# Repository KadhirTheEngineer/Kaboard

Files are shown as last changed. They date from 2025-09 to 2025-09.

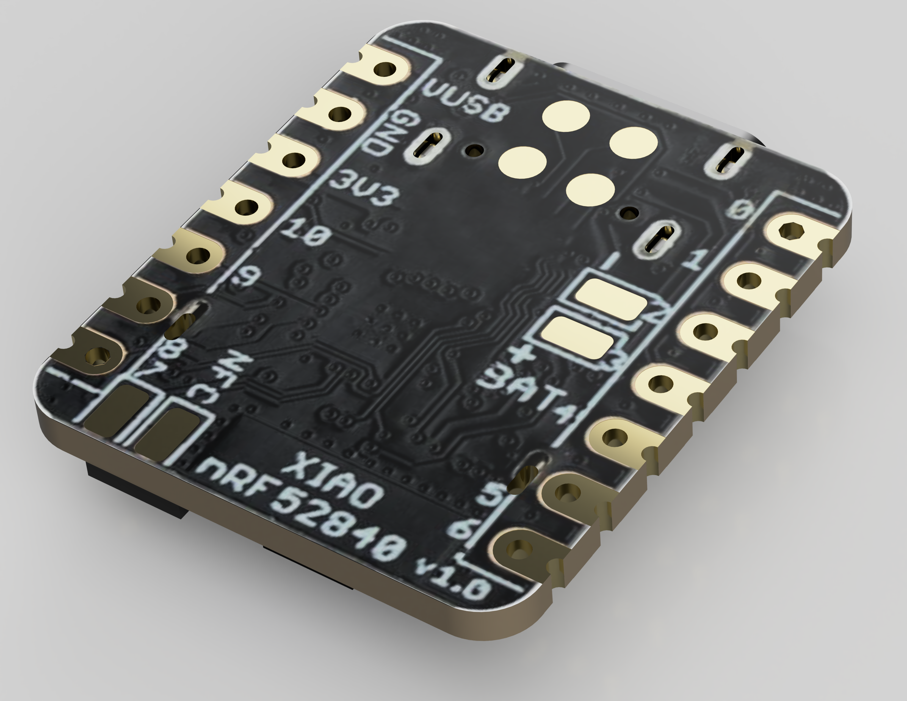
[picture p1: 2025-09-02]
mech/seeed-studio-xiao-nrf52840-1.snapshot.5/XIAO-nRF52840_2023-Jun-02_08-50-46AM-000_CustomizedView56582366354.png

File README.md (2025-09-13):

# Kaboard

An ultra-low profile 36-key wireless split keyboard with the Seeed XIAO nrf52840 dev board. Low power and insane battery life. 



Based on the chocofi and wireless corne.

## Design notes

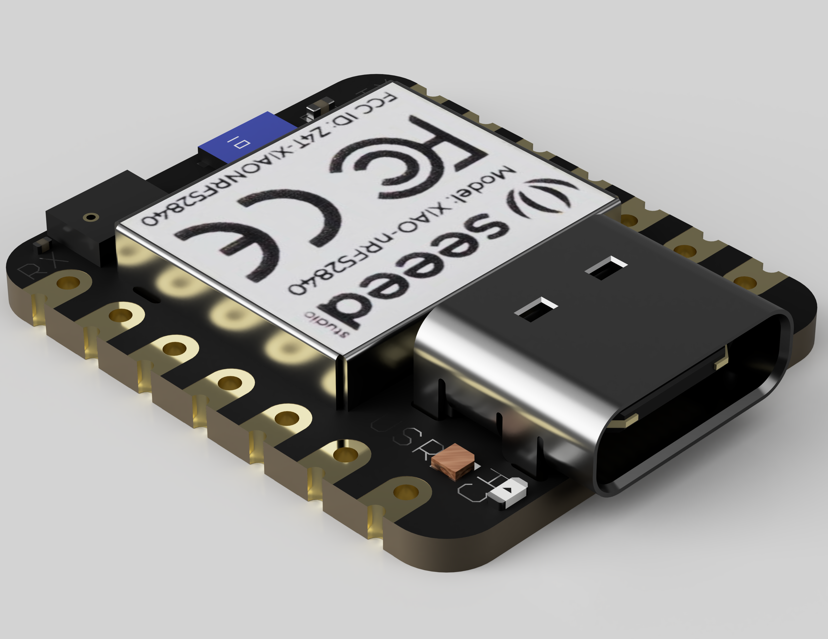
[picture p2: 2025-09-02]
mech/seeed-studio-xiao-nrf52840-1.snapshot.5/XIAO-nRF52840_2023-May-29_10-38-12PM-000_CustomizedView20313148104.png

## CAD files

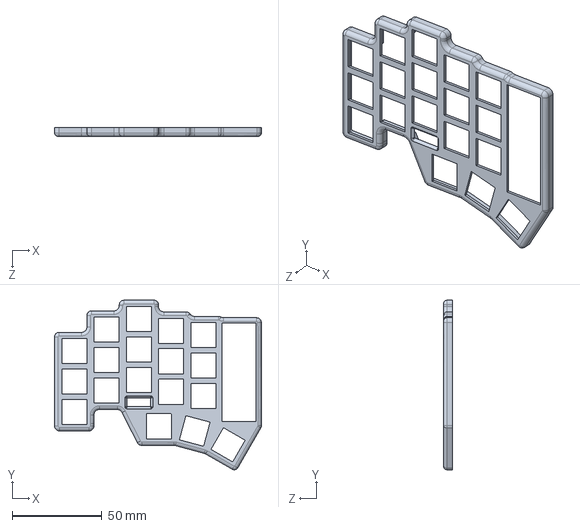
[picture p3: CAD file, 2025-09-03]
mech/case/switchplate_1_2mm_test.SLDPRT
115.4 x 94.6 x 5.00 mm

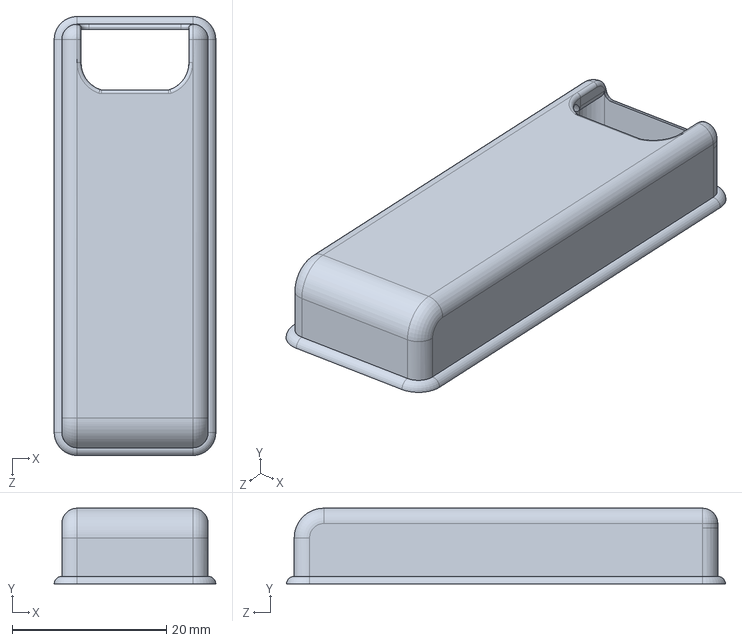
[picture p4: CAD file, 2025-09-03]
mech/Part94.SLDPRT
21.0 x 9.83 x 57.0 mm

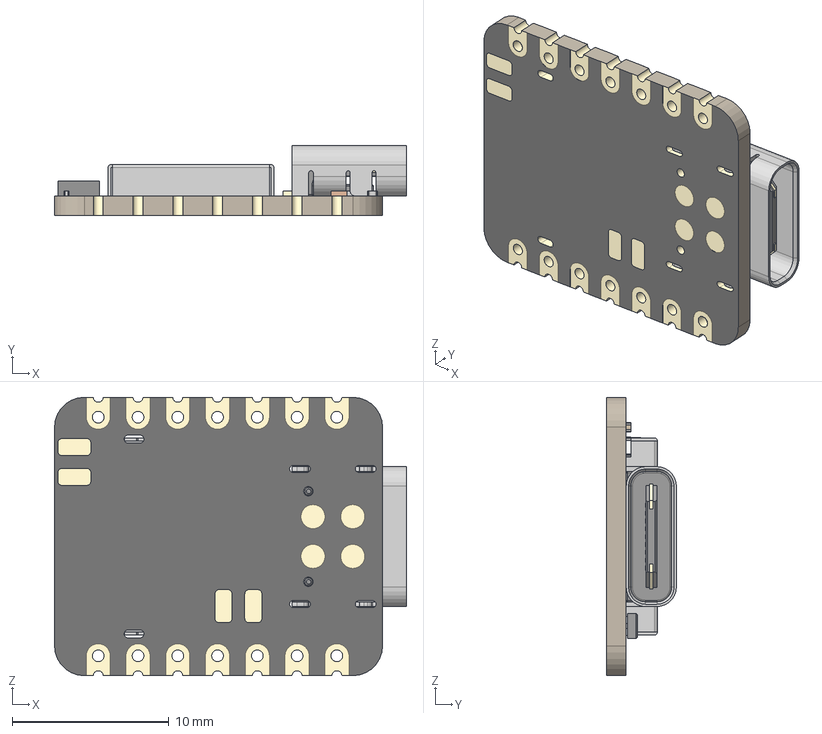
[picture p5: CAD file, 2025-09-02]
mech/seeed-studio-xiao-nrf52840-1.snapshot.5/XIAO-nRF52840 v15.step
22.5 x 4.46 x 17.8 mm
BOSS-EXTRUDE14_8_
BOSS-EXTRUDE7_4_
BOSS-EXTRUDE7_3_
BOSS-EXTRUDE14_4_
BOSS-EXTRUDE14_2_
BOSS-EXTRUDE14_11_
BOSS-EXTRUDE7_7_
BOSS-EXTRUDE14_9_
BOSS-EXTRUDE14_3_
BOSS-EXTRUDE14_7_
MIRROR2
BOSS-EXTRUDE14_5_
BOSS-EXTRUDE14_12_
BOSS-EXTRUDE7_8_
BOSS-EXTRUDE7_1_
BOSS-EXTRUDE14_10_
BOSS-EXTRUDE7_9_
BOSS-EXTRUDE14_6_
BOSS-EXTRUDE14_1_
BOSS-EXTRUDE7_6_
BOSS-EXTRUDE7_2_
CUT-EXTRUDE5
BOSS-EXTRUDE7_5_
Shield
Pins
CAP x 2
ANT1
Silkscreen
CAP 3
LED
USR
2 v1

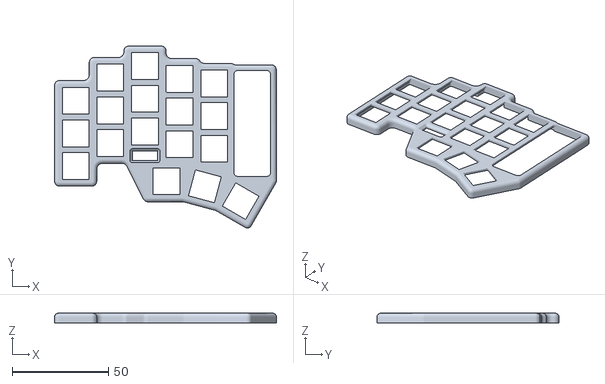
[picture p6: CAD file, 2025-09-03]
test/switchplate.STL
115.4 x 94.6 x 5.00

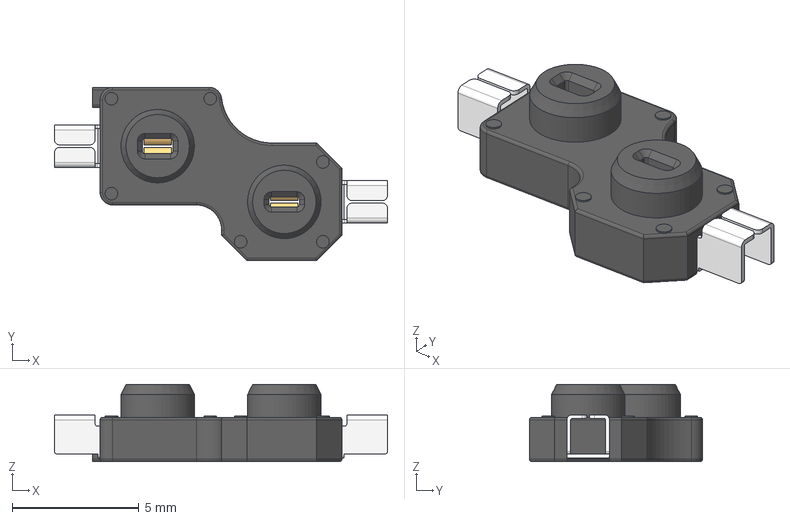
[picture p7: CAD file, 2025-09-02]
mech/choc_socket.step
13.1 x 6.85 x 3.05 mm
choc_body
contact_a1
contact_a2
contact_b
contact_a003
contact_a004
contact_b001

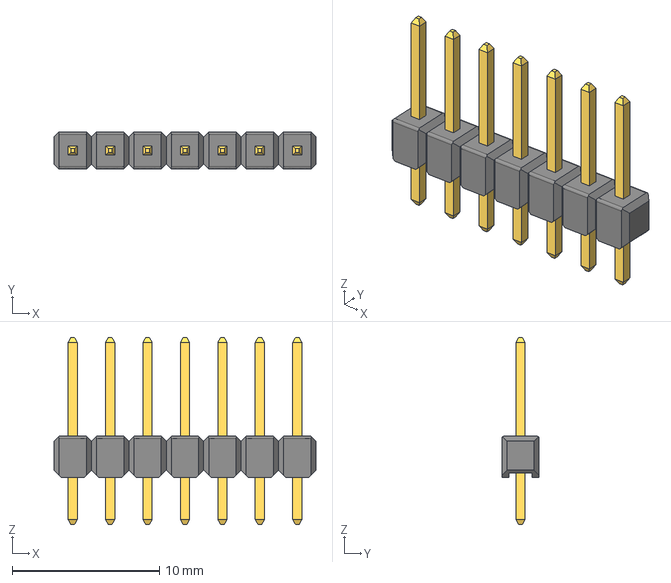
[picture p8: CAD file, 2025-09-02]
mech/Pin Header 1x7 TH Pitch 2.54mm.stp
17.8 x 2.54 x 12.7 mm

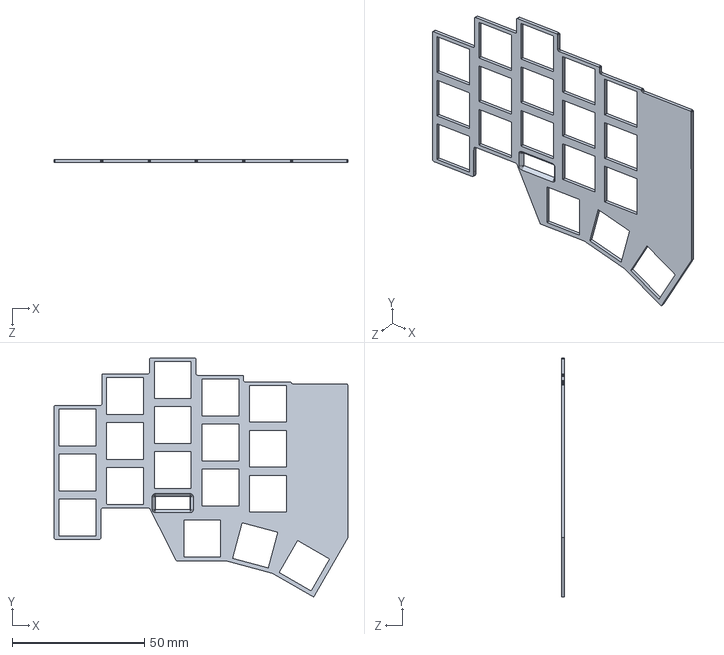
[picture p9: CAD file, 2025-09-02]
test/switchplate_1_2mm_test.SLDPRT
111.1 x 90.3 x 1.20 mm

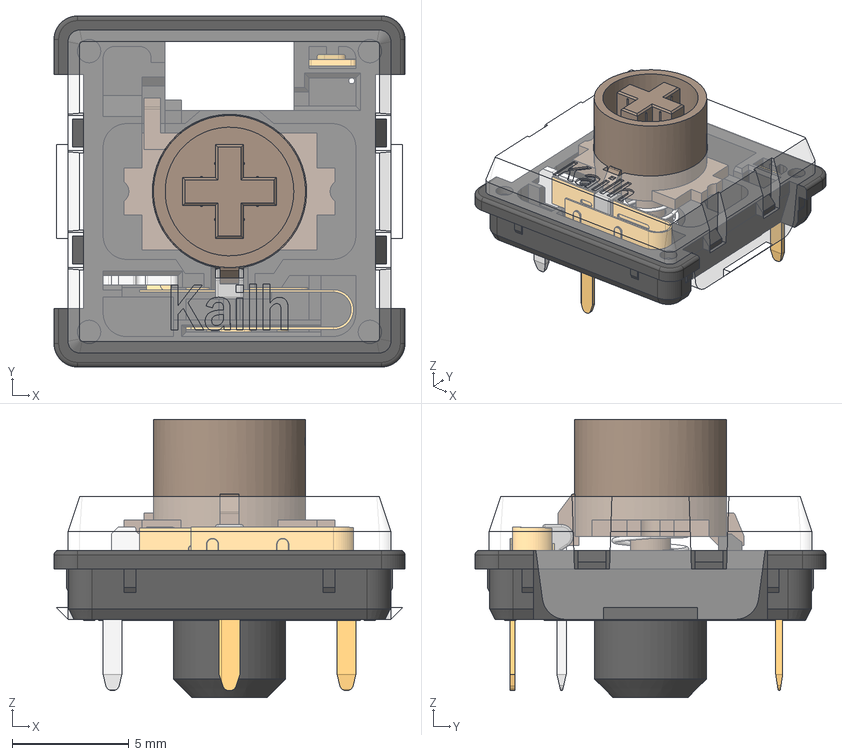
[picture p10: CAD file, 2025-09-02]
mech/brown.step
15.0 x 15.0 x 11.9 mm
bottom
contact
top
stem_tactile
pin1
pin2
pin3
shrunken_spring

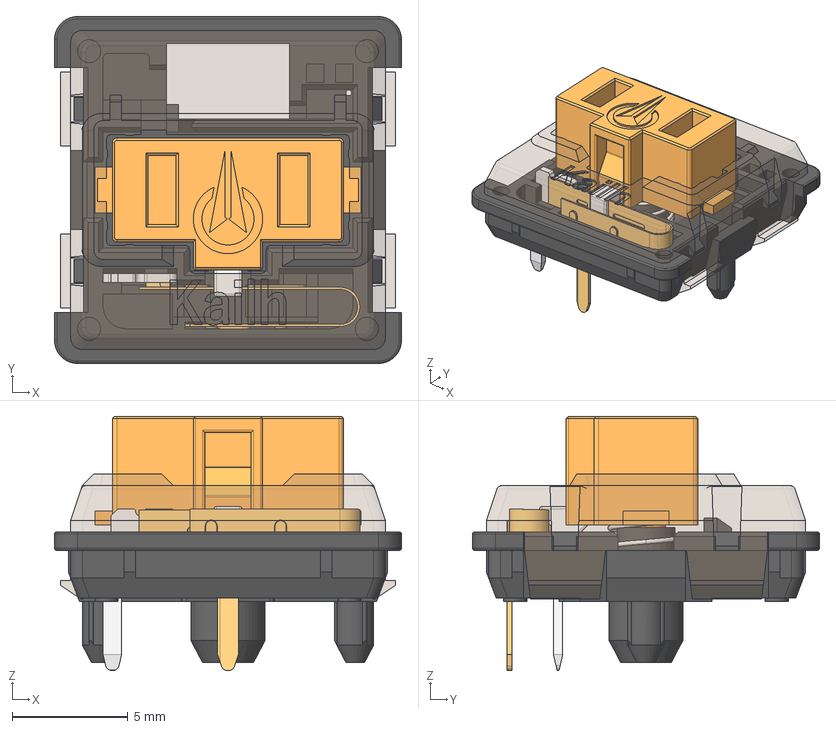
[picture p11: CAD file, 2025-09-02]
mech/sunset_tactile.step
15.0 x 15.0 x 11.0 mm
shrunken_spring
top
pin1
bottom
contact
stem_sunset_tactile
pin2

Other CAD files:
mech/contact001_2.step.SLDASM
mech/contact_a001_2.step.SLDASM
mech/contact_a_2.step.SLDASM
mech/contact_4.step.SLDASM
test/battery box test.STL
test/closed case.STL
mech/kaboard_PCB_1.step.SLDPRT
mech/kaboard_pad_1.step.SLDPRT
mech/contact_a1_2.step.SLDPRT
mech/Kailh Choc FunkMonk 1u.step
mech/choc_socket.SLDASM
mech/contact_a003_2.step.SLDPRT
mech/contact_a004_2.step.SLDPRT
mech/kea-choc-v1-choc-spaced-homing-keycap-1u.step
mech/sunset_tactile.SLDASM
test/switchplate_1_2mm_test.STL

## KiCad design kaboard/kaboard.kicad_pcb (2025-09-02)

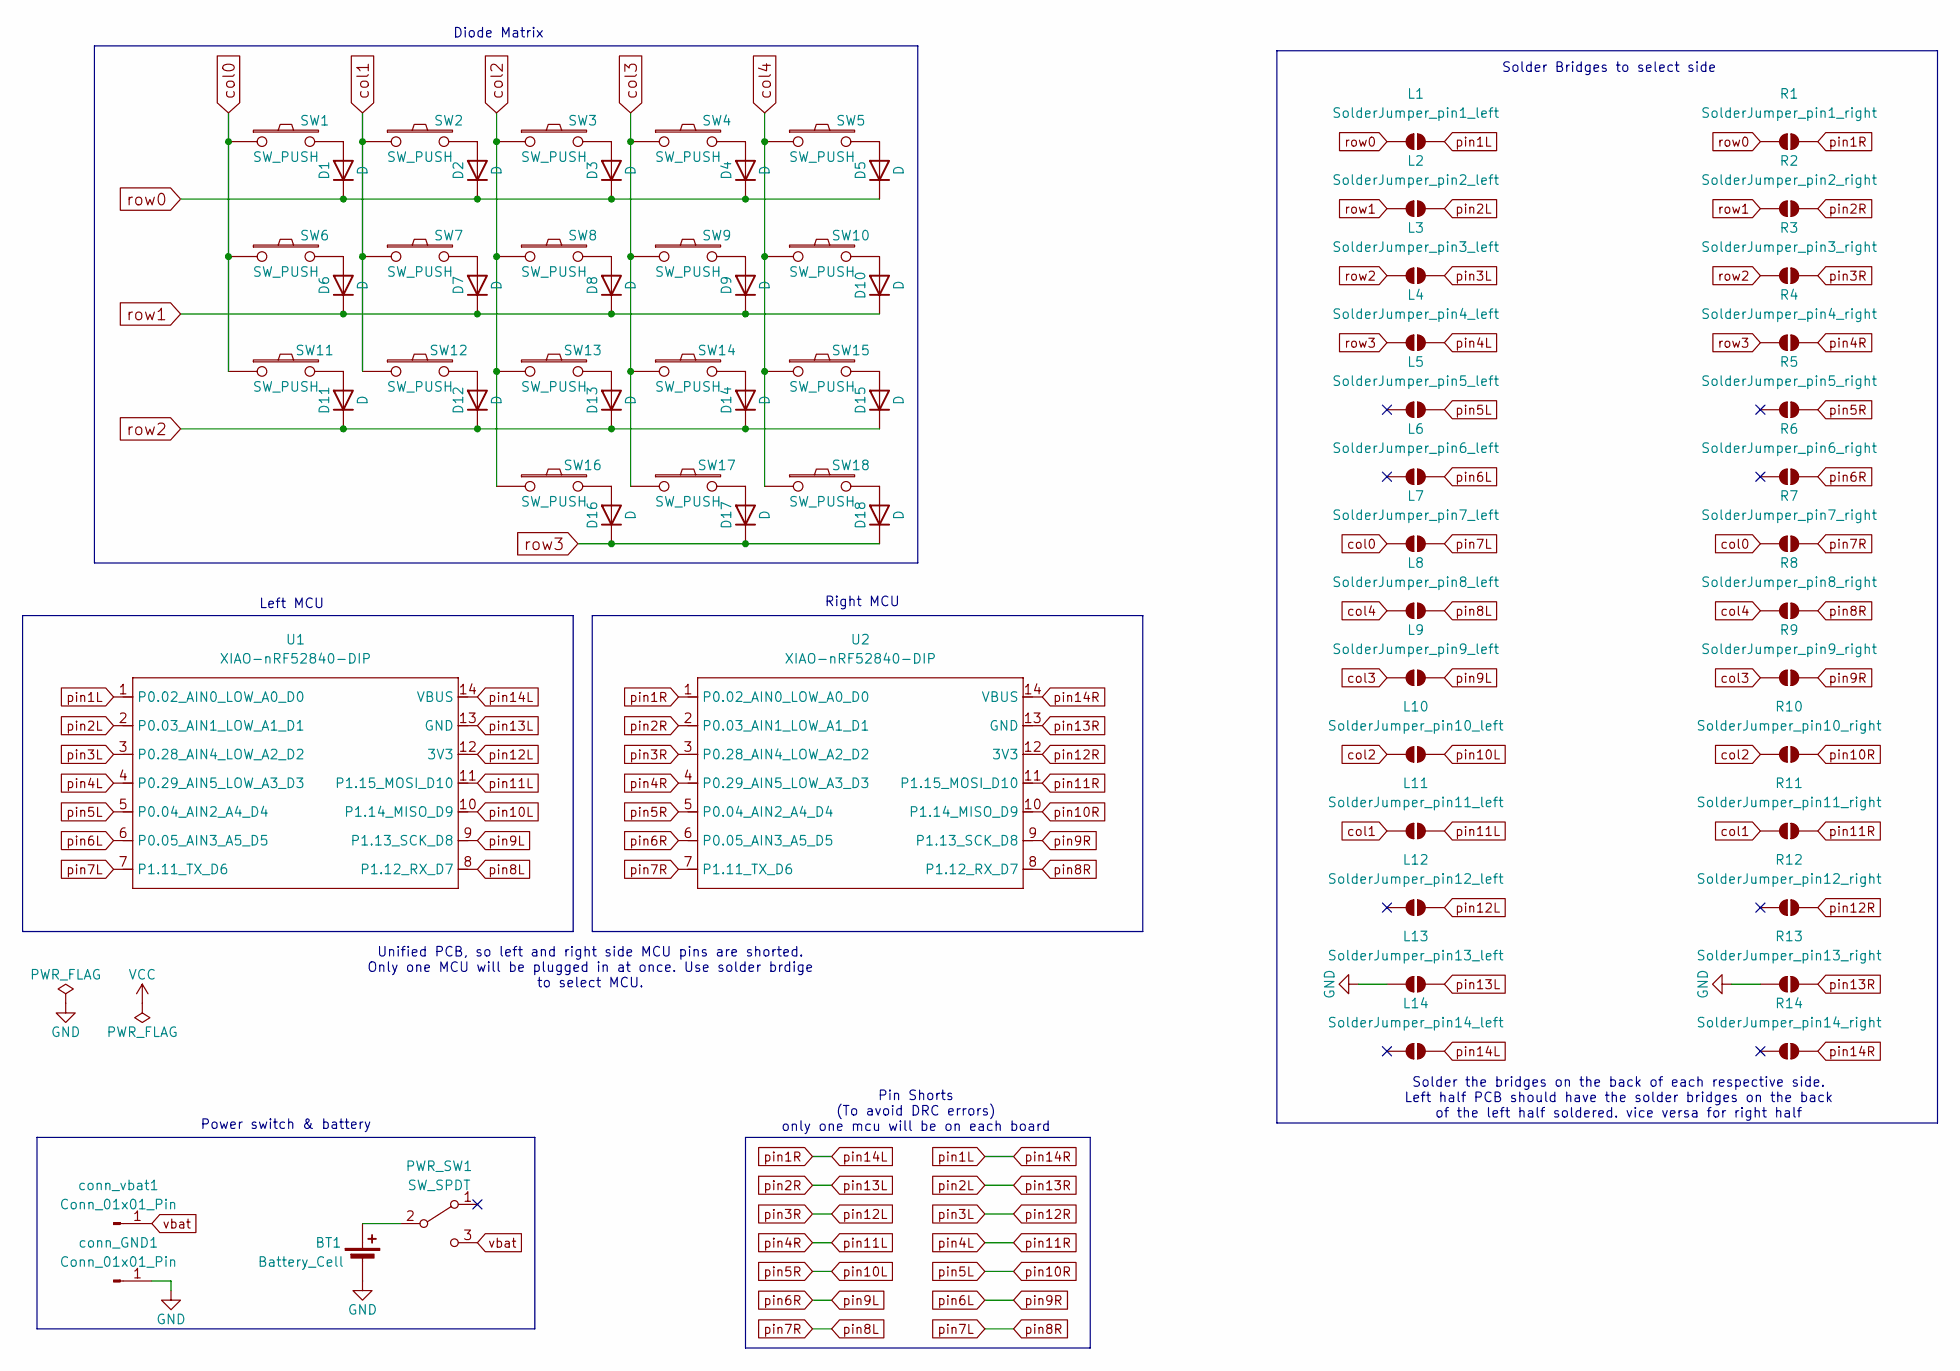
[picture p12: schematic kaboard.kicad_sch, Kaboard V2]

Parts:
BT1: Battery_Cell; Battery_pads_reversible
D1, D2, D3, D4, D5, D6, D7, D8, D9, D10, D11, D12, D13, D14, D15, D16, D17, D18: D; D_SMD_TH
L1: SolderJumper_pin1_left; SolderJumper-2_P1.3mm_Open_TrianglePad1.0x1.5mm
L2: SolderJumper_pin2_left; SolderJumper-2_P1.3mm_Open_TrianglePad1.0x1.5mm
L3: SolderJumper_pin3_left; SolderJumper-2_P1.3mm_Open_TrianglePad1.0x1.5mm
L4: SolderJumper_pin4_left; SolderJumper-2_P1.3mm_Open_TrianglePad1.0x1.5mm
L5: SolderJumper_pin5_left; SolderJumper-2_P1.3mm_Open_TrianglePad1.0x1.5mm
L6: SolderJumper_pin6_left; SolderJumper-2_P1.3mm_Open_TrianglePad1.0x1.5mm
L7: SolderJumper_pin7_left; SolderJumper-2_P1.3mm_Open_TrianglePad1.0x1.5mm
L8: SolderJumper_pin8_left; SolderJumper-2_P1.3mm_Open_TrianglePad1.0x1.5mm
L9: SolderJumper_pin9_left; SolderJumper-2_P1.3mm_Open_TrianglePad1.0x1.5mm
L10: SolderJumper_pin10_left; SolderJumper-2_P1.3mm_Open_TrianglePad1.0x1.5mm
L11: SolderJumper_pin11_left; SolderJumper-2_P1.3mm_Open_TrianglePad1.0x1.5mm
L12: SolderJumper_pin12_left; SolderJumper-2_P1.3mm_Open_TrianglePad1.0x1.5mm
L13: SolderJumper_pin13_left; SolderJumper-2_P1.3mm_Open_TrianglePad1.0x1.5mm
L14: SolderJumper_pin14_left; SolderJumper-2_P1.3mm_Open_TrianglePad1.0x1.5mm
PWR_SW1: SW_SPDT; power_switch_padreverse
R1: SolderJumper_pin1_right; SolderJumper-2_P1.3mm_Open_TrianglePad1.0x1.5mm
R2: SolderJumper_pin2_right; SolderJumper-2_P1.3mm_Open_TrianglePad1.0x1.5mm
R3: SolderJumper_pin3_right; SolderJumper-2_P1.3mm_Open_TrianglePad1.0x1.5mm
R4: SolderJumper_pin4_right; SolderJumper-2_P1.3mm_Open_TrianglePad1.0x1.5mm
R5: SolderJumper_pin5_right; SolderJumper-2_P1.3mm_Open_TrianglePad1.0x1.5mm
R6: SolderJumper_pin6_right; SolderJumper-2_P1.3mm_Open_TrianglePad1.0x1.5mm
R7: SolderJumper_pin7_right; SolderJumper-2_P1.3mm_Open_TrianglePad1.0x1.5mm
R8: SolderJumper_pin8_right; SolderJumper-2_P1.3mm_Open_TrianglePad1.0x1.5mm
R9: SolderJumper_pin9_right; SolderJumper-2_P1.3mm_Open_TrianglePad1.0x1.5mm
R10: SolderJumper_pin10_right; SolderJumper-2_P1.3mm_Open_TrianglePad1.0x1.5mm
R11: SolderJumper_pin11_right; SolderJumper-2_P1.3mm_Open_TrianglePad1.0x1.5mm
R12: SolderJumper_pin12_right; SolderJumper-2_P1.3mm_Open_TrianglePad1.0x1.5mm
R13: SolderJumper_pin13_right; SolderJumper-2_P1.3mm_Open_TrianglePad1.0x1.5mm
R14: SolderJumper_pin14_right; SolderJumper-2_P1.3mm_Open_TrianglePad1.0x1.5mm
SW1, SW2, SW3, SW4, SW5, SW6, SW7, SW8, SW9, SW10, SW11, SW12, SW13, SW14, SW15, SW16, SW17, SW18: SW_PUSH; Kailh_socket_PG1350_reversible
U1, U2: XIAO-nRF52840-DIP
conn_GND1: Conn_01x01_Pin; PinHeader_1x01_P1.00mm_Horizontal
conn_vbat1: Conn_01x01_Pin; PinHeader_1x01_P1.00mm_Horizontal

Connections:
GND: BT1.2 (-), L13.1 (A), R13.1 (A), conn_GND1.1
unnamed: BT1.1 (+), PWR_SW1.2 (B)
unnamed: D1.2 (A), SW1.2
unnamed: D2.2 (A), SW2.2
unnamed: D3.2 (A), SW3.2
unnamed: D4.2 (A), SW4.2
unnamed: D5.2 (A), SW5.2
unnamed: D6.2 (A), SW6.2
unnamed: D7.2 (A), SW7.2
unnamed: D8.2 (A), SW8.2
unnamed: D9.2 (A), SW9.2
unnamed: D10.2 (A), SW10.2
unnamed: D11.2 (A), SW11.2
unnamed: D12.2 (A), SW12.2
unnamed: D13.2 (A), SW13.2
unnamed: D14.2 (A), SW14.2
unnamed: D15.2 (A), SW15.2
unnamed: D16.2 (A), SW16.2
unnamed: D17.2 (A), SW17.2
unnamed: D18.2 (A), SW18.2
col0: L7.1 (A), R7.1 (A), SW1.1, SW6.1, SW11.1
col1: L11.1 (A), R11.1 (A), SW2.1, SW7.1, SW12.1
col2: L10.1 (A), R10.1 (A), SW3.1, SW8.1, SW13.1, SW16.1
col3: L9.1 (A), R9.1 (A), SW4.1, SW9.1, SW14.1, SW17.1
col4: L8.1 (A), R8.1 (A), SW5.1, SW10.1, SW15.1, SW18.1
pin6L: L6.2 (B), R9.2 (B), U1.6 (P0.05_AIN3_A5_D5), U2.9 (P1.13_SCK_D8)
pin6R: L9.2 (B), R6.2 (B), U1.9 (P1.13_SCK_D8), U2.6 (P0.05_AIN3_A5_D5)
pin7L: L7.2 (B), R8.2 (B), U1.7 (P1.11_TX_D6), U2.8 (P1.12_RX_D7)
pin7R: L8.2 (B), R7.2 (B), U1.8 (P1.12_RX_D7), U2.7 (P1.11_TX_D6)
pin10L: L10.2 (B), R5.2 (B), U1.10 (P1.14_MISO_D9), U2.5 (P0.04_AIN2_A4_D4)
pin10R: L5.2 (B), R10.2 (B), U1.5 (P0.04_AIN2_A4_D4), U2.10 (P1.14_MISO_D9)
pin11L: L11.2 (B), R4.2 (B), U1.11 (P1.15_MOSI_D10), U2.4 (P0.29_AIN5_LOW_A3_D3)
pin11R: L4.2 (B), R11.2 (B), U1.4 (P0.29_AIN5_LOW_A3_D3), U2.11 (P1.15_MOSI_D10)
pin12L: L12.2 (B), R3.2 (B), U1.12 (3V3), U2.3 (P0.28_AIN4_LOW_A2_D2)
pin12R: L3.2 (B), R12.2 (B), U1.3 (P0.28_AIN4_LOW_A2_D2), U2.12 (3V3)
pin13L: L13.2 (B), R2.2 (B), U1.13 (GND), U2.2 (P0.03_AIN1_LOW_A1_D1)
pin13R: L2.2 (B), R13.2 (B), U1.2 (P0.03_AIN1_LOW_A1_D1), U2.13 (GND)
pin14L: L14.2 (B), R1.2 (B), U1.14 (VBUS), U2.1 (P0.02_AIN0_LOW_A0_D0)
pin14R: L1.2 (B), R14.2 (B), U1.1 (P0.02_AIN0_LOW_A0_D0), U2.14 (VBUS)
row0: D1.1 (K), D2.1 (K), D3.1 (K), D4.1 (K), D5.1 (K), L1.1 (A), R1.1 (A)
row1: D6.1 (K), D7.1 (K), D8.1 (K), D9.1 (K), D10.1 (K), L2.1 (A), R2.1 (A)
row2: D11.1 (K), D12.1 (K), D13.1 (K), D14.1 (K), D15.1 (K), L3.1 (A), R3.1 (A)
row3: D16.1 (K), D17.1 (K), D18.1 (K), L4.1 (A), R4.1 (A)
vbat: PWR_SW1.3 (C), conn_vbat1.1

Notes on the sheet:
Solder Bridges to select side
Solder the bridges on the back of each respective side. Left half PCB should have the solder bridges on the back of the left half soldered. vice versa for right half
Diode Matrix
Left MCU
Unified PCB, so left and right side MCU pins are shorted. Only one MCU will be plugged in at once. Use solder brdige to select MCU.
Pin Shorts (To avoid DRC errors) only one mcu will be on each board
Right MCU
Power switch & battery

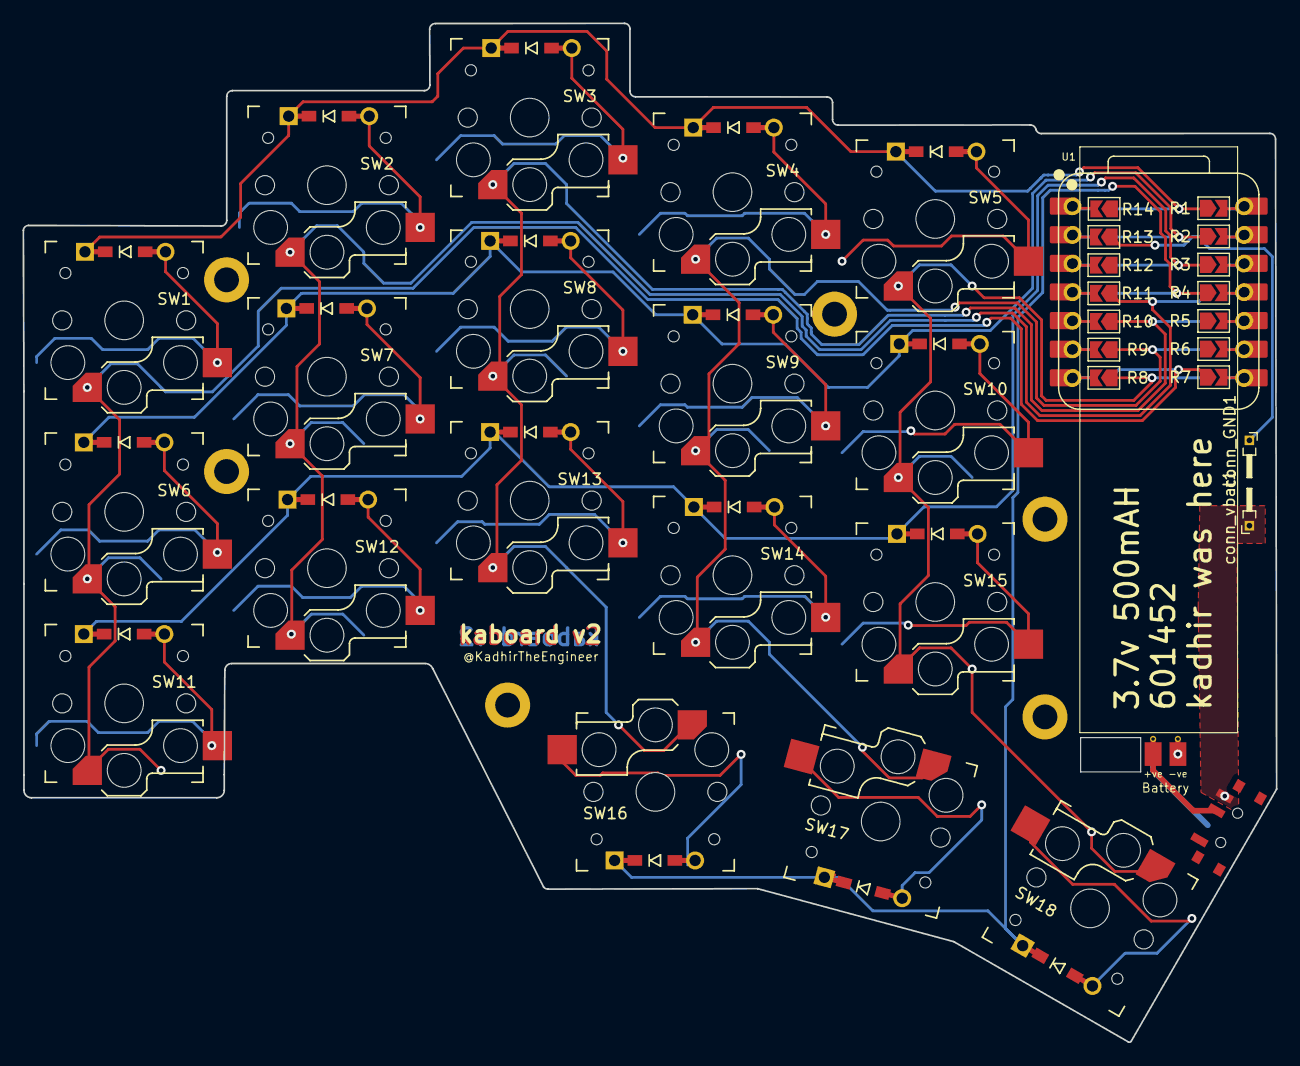
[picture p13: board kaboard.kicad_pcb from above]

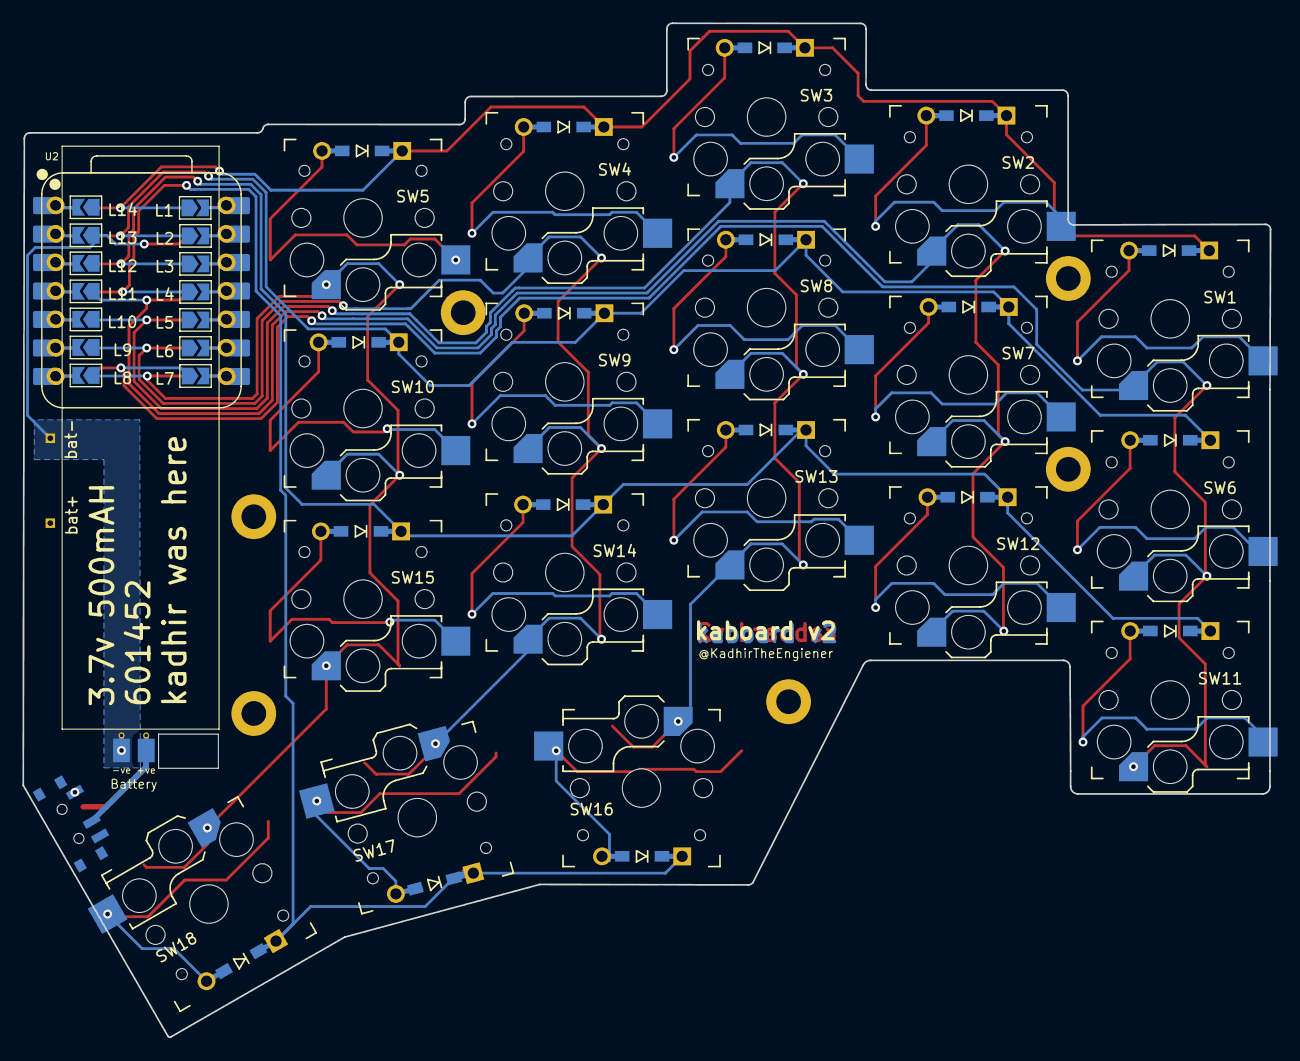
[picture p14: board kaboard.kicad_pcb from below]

Board: 2 copper layers, 111.3 x 90.4 mm, 76 parts (15 on the bottom side), 44 nets.

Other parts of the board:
h2: h2; LEGO_HOLE
h3: h3; LEGO_HOLE
h4: h4; LEGO_HOLE
h5: h5; LEGO_HOLE
h6: h6; LEGO_HOLE
h7: h7; LEGO_HOLE

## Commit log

2025-09-02 mechanical stuff
    [Kailh Choc FunkMonk 1u.step, Pin Header 1x7 TH Pitch 2.54mm.stp, XIAO-nRF52840 v15.step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]
2025-09-02 pcb updates
    [kaboard.kicad_pcb]
2025-09-02 case test
    [closed case.STL, switchplate_1_2mm_test.SLDPRT]
2025-09-03 battery test
    [Part94.SLDPRT, battery box test.STL, switchplate_1_2mm_test.SLDPRT]
2025-09-03 switchplate test
    [switchplate.STL]
